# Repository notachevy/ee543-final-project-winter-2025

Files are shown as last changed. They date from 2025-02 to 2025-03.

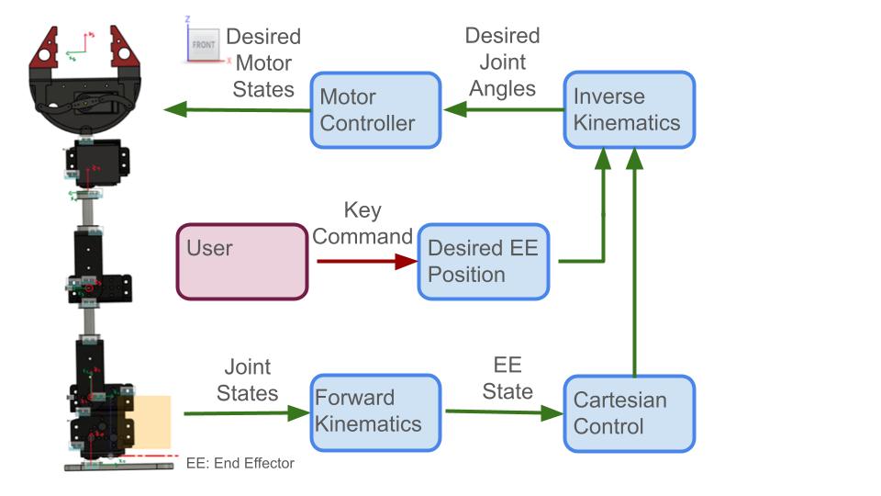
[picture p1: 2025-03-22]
Control Diagram.jpg

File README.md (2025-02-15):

# ee543-final-project-winter-2025
Devansh Bajwala, Nathan Ford, and Ahn Nguyen

## Instruction Document: https://docs.google.com/document/d/1Ubh2IKTzpHcgaXKEUiXXJ3vKN5BsKgkgP82SdHQJfz0/edit?tab=t.0
## Google Drive: https://drive.google.com/drive/folders/1BTNabRJ4Ctvt-MD4dDE4fDTYfD7tWb_S?usp=drive_link

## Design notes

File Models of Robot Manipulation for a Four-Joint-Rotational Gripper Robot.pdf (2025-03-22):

University of Washington Internal Report

# Models of Robot Manipulation for a Four-Rotational-Joint Gripper Robot

Devansh Bajwala
Dept. Of Mechanical Engineering University of Washington
Seattle, United States
db7529@uw.edu

Nathan Ford
Dept. Of Electrical Engineering University of Washington
Seattle, United States
naford@uw.edu

Anh Nguyen
Dept. Of Electrical and Computer Engineering
University of Washington
Seattle, United States
anguye22@uw.edu

Abstract— The field of robotics consists of many groundbreaking robotic advancements, but the robot detailed in this report is not one of them. The robot detailed in this report is a four-rotational-joint gripper robot that uses forward kinematics to enable joint-based control and inverse kinematics to enable cartesian control of the end effector. The robot was created to detail the basic principles of 3D robot manipulation. Rather than being a standard 6 degrees of freedom, the robot is instead 4 degrees of freedom. The 4 degrees of freedom present several challenges to the design and implementation process. The reachable workspace is approximated with a Monte-Carlo simulation that calculates whether a desired end effector position is achievable. The robot is modelled in software and created in physical hardware. The GitHub repository detailing the code and files necessary
to | recreate | the | robot | can | be | found | at | this | link:
https://github.com/notachevy/ee543-final-project-winter-2025.git. The project is based upon a template project provided in the GitHub repository found at this link: https://github.com/HaonanPeng/EE543-Robot-Manipulation-Project.git [1].

Keywords— Robotics, cartesian control, reachable workspace, rotational joints, link frame assignment, DH table, DH parameters, forward kinematics, inverse kinematics, IKBT, Monte-Carlo simulation.

I. INTRODUCTION
The study of robotics consists of mathematically modelling the positions of and relationships between links and joints to achieve interactions with the environment through an end effector. Robotic arms have a base that defines their set connection to a location and an end effector that allows it to interact with its environment. For our robot, the end effector is set as a gripper that is able to open and close, but many types of end effectors exist.
The current field of robotics is generating significant improvements in the medical field such as surgical robots. Across all fields, machine learning and artificial intelligence (AI) are helping robots interact with their environment by both aiding in physical training and allowing for virtual training through generated scenarios. Some robots focus on modelling human behaviour, but a majority of robots do not attempt to mimic human behavior but rather accomplish a task in an efficient manner. For 3D cartesian movement, a robotic arm is excellent as it usually provides 6 degrees of freedom, a perfect match to a 3-dimensional space. Advanced robotic arms have 7 degrees of freedom to allow for multiple arm positions, yielding the same end effector position. The advantage of multiple arm positions is that the robot arm can manipulate around obstacles and take predefined paths. The complexity when adding a 7th degree of freedom increases dramatically as the arm will always have multiple solutions, and control code will need to be written to determine the best solution instantaneously and over a pathway.
The more advanced robots will also utilize velocity control using the Jacobian. Velocity control allows for a robot arm to dictate its linear speed with calculations from its angular speed. The advantages to velocity-based control methods are smoother trajectories with fewer overshoots that help protect the robot and its surroundings. The generated trajectories have predefined acceleration paths, and if using a parabolic blend trajectory generation, faster movements from desired locations can be achieved.

II. LINK FRAME ASSIGNMENT AND DH PARAMETERS
To begin work modeling the robot, the graphical and mathematical representations of the robot must be defined. The robot is defined graphically by its link frame assignment and mathematically by its DH parameters, represented in a DH table.
A. Link Frame Assignment
The first step in defining a robot graphically is to define the base frame. The base frame for the robot is defined as the point the center point of the rotational disk meets the base. The +Z axis is defined as a perpendicular line that runs through the center of the rotation disk in the direction of the motor. The next step is to define the location of the final frame (frame five). The final frame is defined as a point in the middle of the grabber with the +Z axis defined as the direction facing outwards from the gripper. The +Z axis assignments can be seen in Fig. 1.
The +X direction of the base frame is set to be parallel to the +X direction of frame one. The +X direction of frame five is defined as parallel to the +X direction of frame four. The rest of the +X directions are assigned using standard DH assignment principles. The +Y directions are omitted from representation as they can be determined by taking the cross product of +Z cross +X. The +X assignments can be seen in Fig. 1.

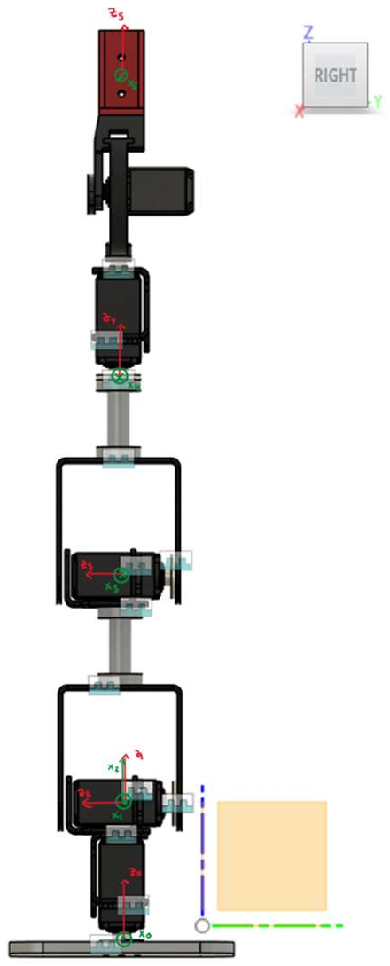
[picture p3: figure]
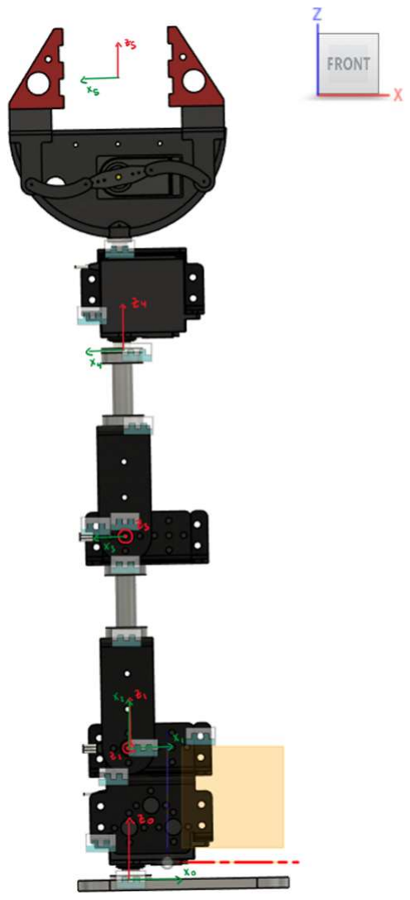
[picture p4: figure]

Fig. 1. Link frame assignment overlayed onto 3D model of robot. Perspective cube in top right corner represents world view orientation and direction. Red, green, and blue dashed lines represent world view axis in X, Y, Z format respectively. The yellow plane represents the face of the model (as seen in the perspective cube in the top right corner).

B. DH Table and Parameters
To define a robot mathematically, its graphical representation can be used to define a set of parameters representing the rotational and translational transforms necessary to go from one frame to the next frame. Standard DH parameter assignment is used to get the DH parameters shown in Table I.

TABLE I. DH PARAMTERS

Joint
N-1 N

DH Parameters
| A (mm) | α (deg) | d (mm) | θ (deg)
0 1 | 0 | 0 | 62.8 | θ
1 2 | 0 | 90 | 0 | θ
2 3 | 101 | 0 | 0 | θ
3 4 | 0 | 90 | 87.5 | θ
4 5 | 0 | 0 | 125 | 0
C. Forward Kinematics Simulation
The previously provided CAD model of the robot arm is excellent at visualizing what the arm will look like but poor at indicating how the arm will move and showing the current state of the robot. To visualize the frames of the arm while it is moving, a forward kinematics simulation models the motion of the arm. The simulation shows the robot arm modelled as simple links in an empty 3D space. The length of the virtual link joints is proportional to the size of the actual arm links. Each link frame is represented with a red arrow indicating the +Z direction and a blue arrow indicating the +X direction. A snapshot of the simulation can be seen in Fig. 2.

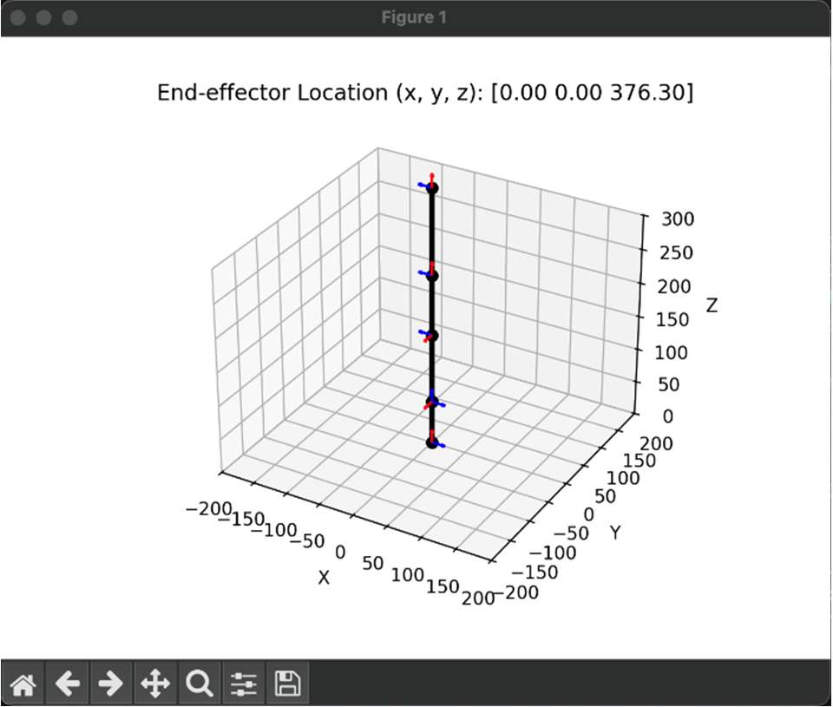
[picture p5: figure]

Fig. 2. Forward kinematics simulation showing a virtual representation of the actual arm. The virtual link lengths are proportional to the actual link lengths. Each link frame assignment is shown by indicating the +Z direction with a red arrow and the +X direction with a blue arrow. The robot is shown in the “home” position, or its state when all the servos are homed and their theta values are set to 0.
The simulation is computed using a numeric solving of the forward kinematics equations. The forward kinematics are updated every time a joint angle is changed to display the position of the actual arm in real time. The details of determining the forward kinematics are given in the next section, Forward Kinematics.

III. FORWARD KINEMATICS
Forward kinematics is the process of applying the state of a robot represented by its rotational joint angles and translational joint distances to determine the orientation and location of the end effector in space. For the four-rotational-joint gripper, only rotational joints are used so only rotational joints will be discussed. Translational joints behave mathematically similar to rotational joints except the “d” value from the DH table is variable while the “θ” value is fixed.
Forward kinematics will provide the end effector position given the input joint angles result in a valid orientation. The collection of all valid robot joint angles is called the reachable workspace. The workspace is a complicated 3D space, so a Monte-Carlo simulation is run to visualize and approximation of the workspace. The Monte-Carlo simulation samples many random valid combinations of joint angles to produce a point-cloud of valid end effector positions, giving a visualization of valid end effector positions.
A. Symbolic Forward Kinematics
To computationally save time to calculate the forward kinematics for every instance of the robot, the symbolic representation of the end effector can be found in terms of the angles of its joints. The symbolic representation begins as a collection of transformation matrices that contain a rotation matrix and a position vector. These transformation matrices use the DH table to generate a transformation matrix for the transformation between every frame, 01, 12, 23, 34, and 45. Because each transformation is calculated in the current frame, the total transformation matrix from the base to the end effector, 05, can be found by post-multiplying the transformation matrices in order. The individual transformation matrices are given in Fig. 3.

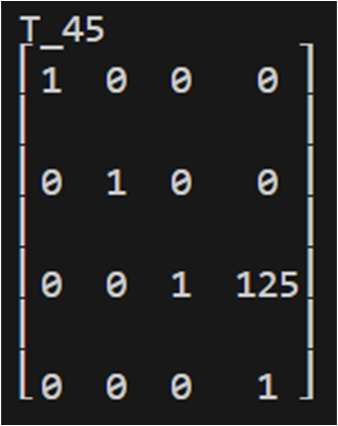
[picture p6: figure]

Fig. 3. Forward kinematics transformation matrices. The transformation matrices represent the rotation matrix (the upper left 3x3 matrix) and the position vector (the upper right 1x3 matrix). From top to bottom, the figures are: a. general transformation matrix form showing the location of the rotation matrix and position vector with a graphical representation of the transformaiton [2], b. the transformation matrix from frame 0 to frame 1, c. the transformation matrix from frame 1 to frame 2, d. the transformation matrix from frame 2 to frame 3, e. the transformation matrix from frame 3 to frame 4, f. the transformation matrix from frame 4 to 5.
The overall transformation matrix to go from the base frame to the end effector frame, 05, is quite complicated. The full transformation matrix in Fig. 4 is included for completeness, but for ease of use, the “forward_k.py” file should be run from the project GitHub to acquire the matrix if it is to be used. The full transformation matrix is useful as it allows for a simpler calculation of end effector position given joint angles. Only twelve values need to be calculated given four variables to determine the orientation and location of the end effector. The symbolic representation speeds up calculations as numeric versions of each individual transformation matrix do not need to be multiplied together.

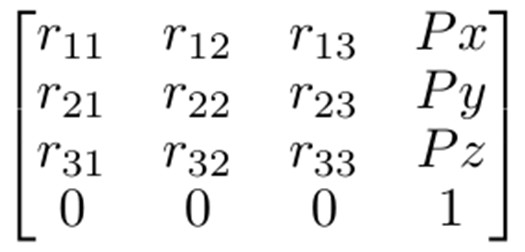
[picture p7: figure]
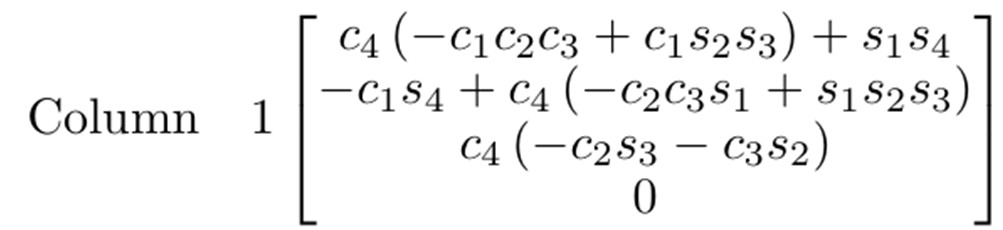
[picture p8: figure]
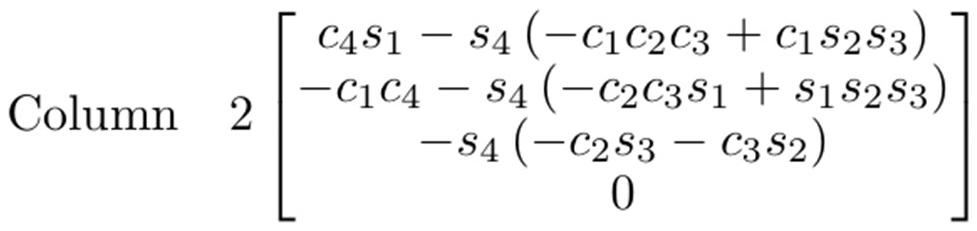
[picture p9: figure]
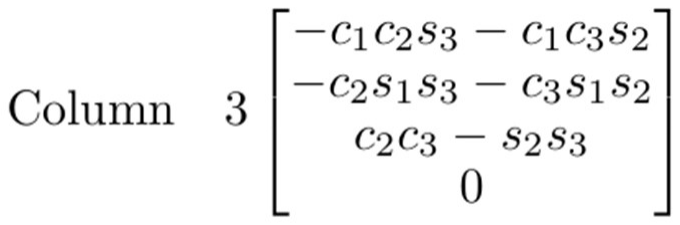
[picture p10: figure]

Fig. 4. The overall transformation matrix from the base frame to the end effector in general form (top). The individual columns are broken up to enhance

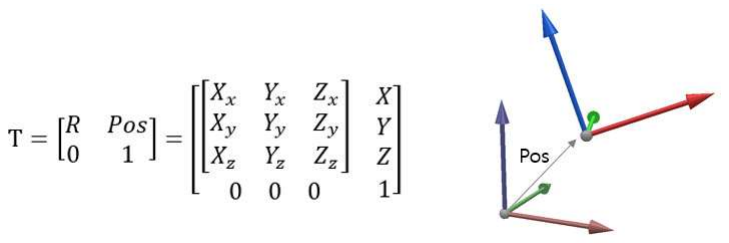
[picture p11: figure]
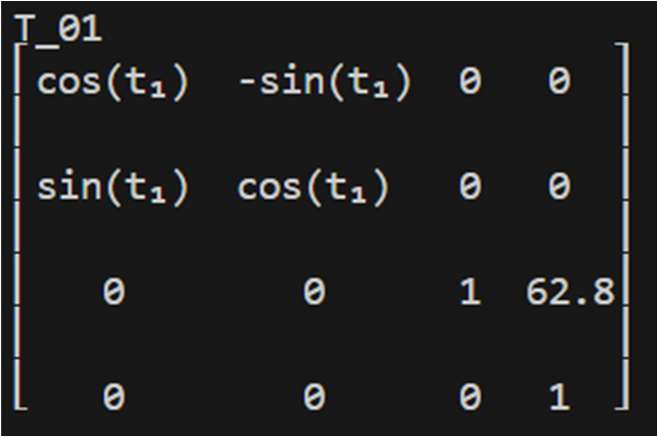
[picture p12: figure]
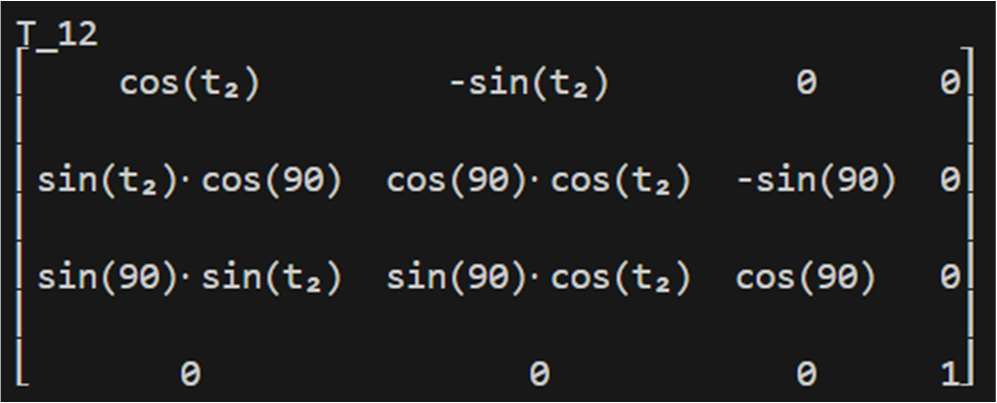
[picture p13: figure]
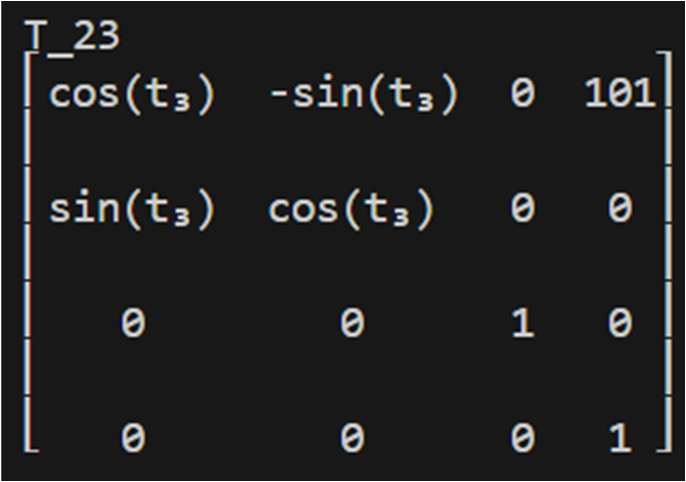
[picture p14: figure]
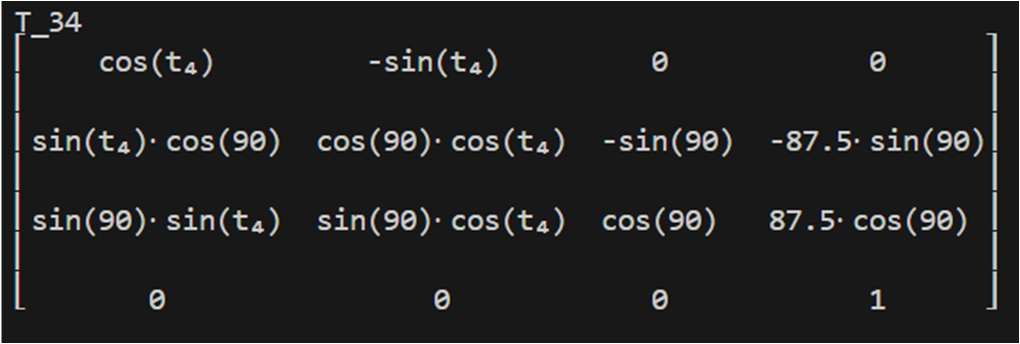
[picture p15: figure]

the readability of the symbolic forward kinematics matrix. The columns are numbered 1-4 and read from left to right.

B. Monte-Carlo Simulation
The Monte-Carlo simulation has two uses. The first use is to visualize the workspace and the second is to check if a given point is within or outside the workspace.
Visualizing the workspace is done by taking a large collection of random combinations of joint angles and using the previously discussed symbolic forward kinematics to determine the resulting end effector location. For this simulation, the orientation of the end effector is ignored as the workspace is defined as the region the end effector can reach. Each iteration of the simulation plots one point in 3D space for a valid joint combination. With numerous iterations, a point cloud forms that shows the shape of the 3D workspace. The Monte-Carlo workspace approximation is shown in Fig. 5. The simulation yields a workspace that appears spherical. In practice, the arm is situated on a flat physical surface that prevents the arm from reaching points underneath it. In theory, the arm can reach all points within an outer boundary sphere and outside and inner boundary sphere (components cannot physically overlap).

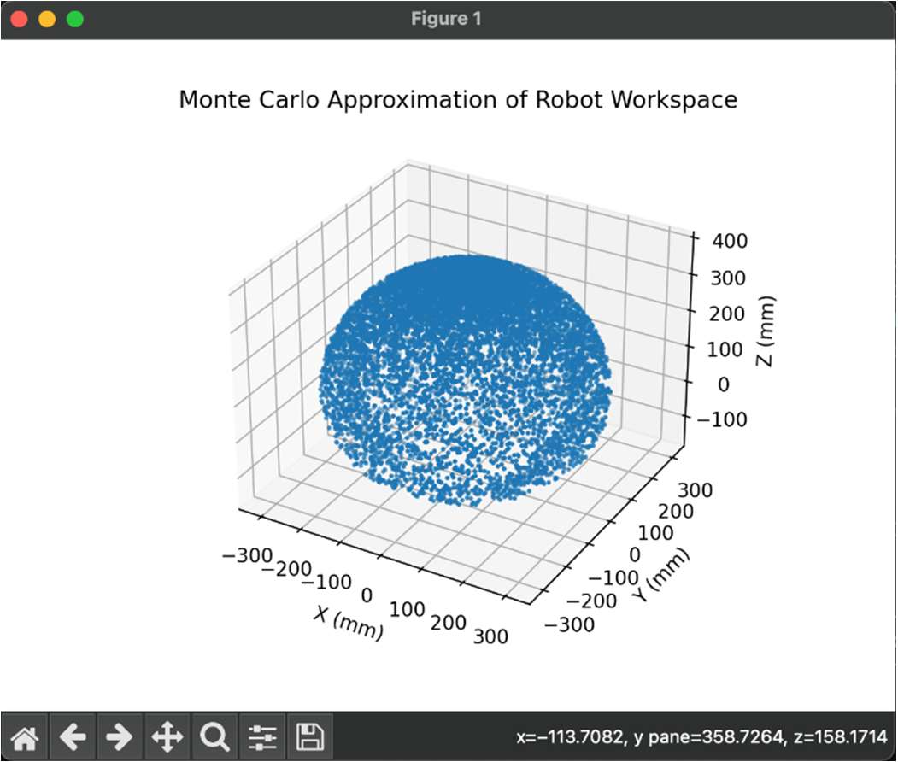
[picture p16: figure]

Fig. 5. Monte-Carlo simulation showing a point cloud that approximates the workspace of the robot by plotting the end effector location by plugging in angles into the symbolic forward kinematics and solving using numerous iterations of combinations of valid joint angles.
The second use of the Monte-Carlo simulation is to determine whether a given point is reachable in the workspace. Determining whether a point is within the workspace is helpful in determining the validity of a combination of joint angles to ensure the safety of the robot and the users nearby. To calculate whether the point is within the workspace, the algorithm will sample the nearest points in the cloud and create vectors between the test point and each closest point. The algorithm will then compare the angle between the closest vectors to see whether or not the point is within the tangent of the workspace. To accomplish this, any angle above 85 degrees is assumed close enough to 90 degrees to warrant being within the workspace.

To test the algorithm, three points are given and the algorithm needs to determine whether or not the points are within the workspace. The results are shown in Fig. 6 and Table II.

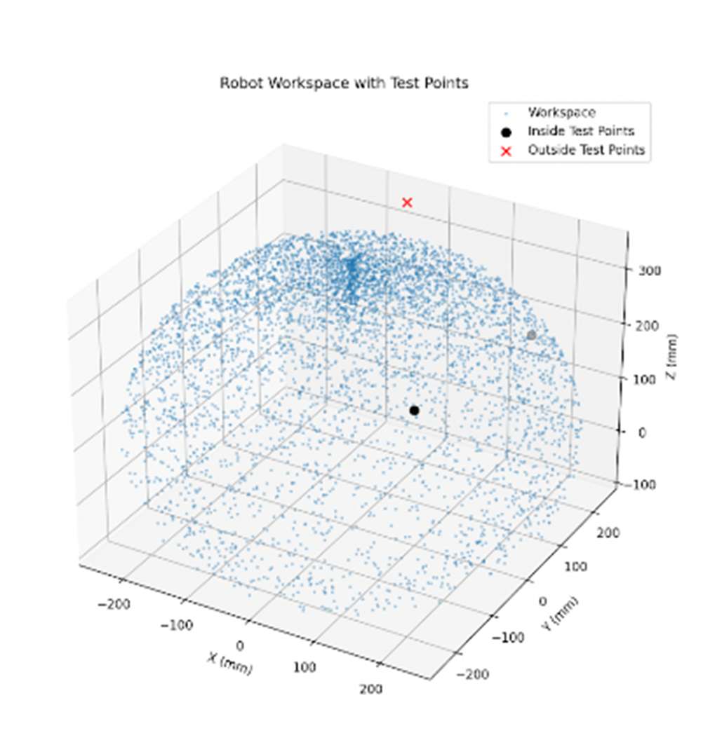
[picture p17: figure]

Fig. 6. Monte-Carlo workspace simulation showing test points and whether or not they are within the workspace.

TABLE II. | MONTE-CARLO WORKSPACE TEST POINTS
Point | Point Parameters
X | Y | Z | Inside or Outside Workspace
1 | 70 | 50 | 100 | Inside
2 | 175 | 150 | 400 | Outside
3 | 180 | 180 | 200 | Inside

IV. INVERSE KINEMATICS AND CARTESIAN SPACE CONTROL
Inverse kinematics is both more complicated and more useful than forward kinematics. Inverse kinematics is the inverse of forward kinematics, where a known end effector position is used to determine the joint angles to produce the desired position and rotation. Unfortunately, for our robot, we have four joints and only three known values, X, Y, and Z. This means our situation is underspecified and there may be multiple solutions. This trouble arises from our robot only having 4 degrees of freedom rather than the standard 6 degrees of freedom associated with X, Y, Z, roll, pitch, and yaw. To keep functionality of our robot, the final rotational joint is perpendicular to the direction of motion of the grabber. This means with one rotational joint; we can control our orientation and do not need to solve for all 6 degrees of freedom.
For our robot, we explored both analytical inverse kinematics and numerical inverse kinematics to achieve

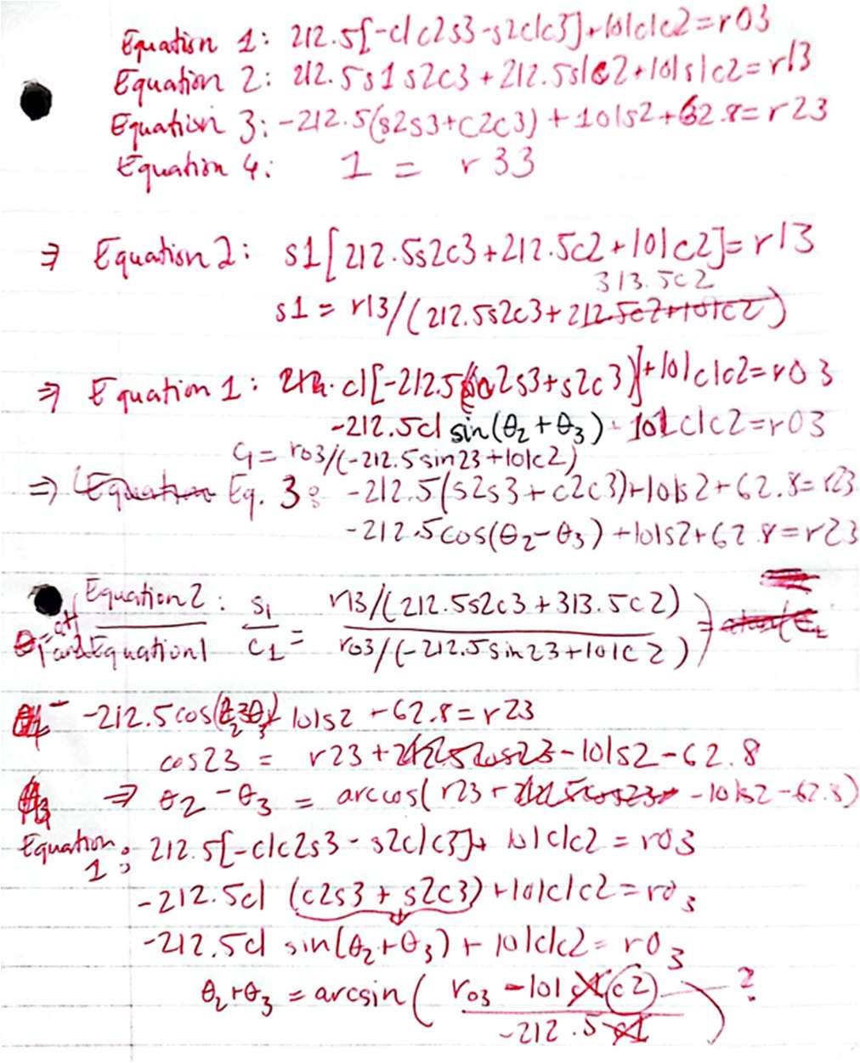
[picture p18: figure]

cartesian control rather than joint control. The analytical inverse kinematics is too complicated to be handled by solvers such as Wolfram-Alpha, so it needed to be attempted manually. Our attempt to solve the inverse kinematics by hand was unsuccessful and we ended up using a prebuilt IKBT library made by Professor Blake Hannaford to compute the analytical inverse kinematics solution [3]. For the actual implementation, numeric inverse kinematics was solved using an optimizer to minimize the error between desired and actual end effector position with respect to joint angles.
With solved inverse kinematics, the end goal of controlling the end effector in cartesian space can be achieved. Cartesian control is more intuitive for operators than joint control, so it is preferred even though it is more computationally difficult.
A. Analytical Inverse Kinematics
To quickly solve the joint angles required, an analytical solution will yield symbolic representations of the joint angles. These symbolic representations are significantly faster to compute than a numeric approximation of joint angles. To compute the analytical solution to the inverse kinematics, the forward kinematics solution from the base to the end effector is taken and solved for the joint angles.
To solve for the joint angles, there need to be known values in the transformation matrix. Unfortunately, we are assuming for our cartesian control that we do not have control over the orientation of the end effector directly. To orient our end effector, we are using the rotational joint connected to the gripper, joint 4. Having control over X, Y, Z, and roll (in the direction of +Z axis) means our robot arm only has 4 degrees of freedom rather than the standard 6 degrees of freedom in 3D space. Because we are solving our inverse kinematics for the cartesian control, we are assuming the only three known values are X, Y, and Z. When solving for the joint angles, joint 4 does not impact the end effector position, so we only need three equations to solve for joints 1, 2, and 3. The three equations that dependent upon joints 1, 2, and 3 conveniently are the equations for X, Y, and Z. With these equations to solve determined, we began the task of isolating for each joint angle. Unfortunately, the joint angle dependencies made it too difficult to isolate the variables by hand. With the equations isolated, we tried an online solver to solve for the joint angles, but the system of equations proved too difficult for Wolfram Alpha to solve as well. The manual and Wolfram Alpha attempts to solve for the joint angles are shown in Fig. 7.

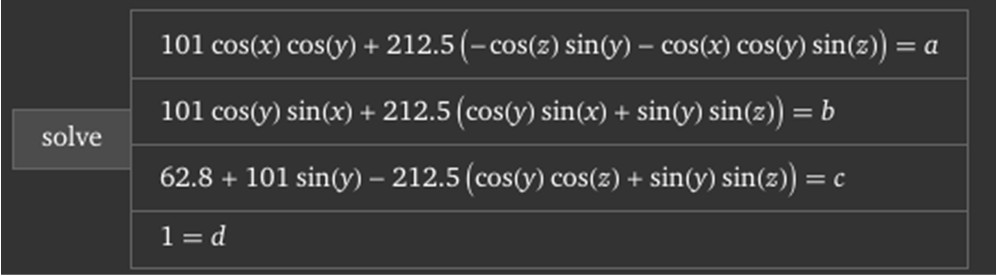
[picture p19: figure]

Fig. 7. Manual (top) and Wolfram Alpha (bottom) attempts at solving for the joint angles 1, 2, and 3. The manual attempt details attempts at solving for the joint angles theta 1 with theta 2 and theta 3 dependenceies. Theta 2 and theta 3 could not be isolated from each other. The Wolfram Alpha attempt at solving did not yield a solution or formal attempt as the complexity is greater than it can compute.
Because the manual analytical inverse kinematics was unsuccessful, we turned to an existing library to assist with solving our inverse kinematics. The library is based upon Professor Blake Hannaford’s work in solving inverse kinematics with symbolic behaviour trees (called IBKT in the given GitHub link above). The process involves finding closed-form solutions to inverse kinematics problems with actions in behavior trees. The library generates a report called “IK_Report_Template” that is visible on our project GitHub repository. Fig. 8 Shows the joint angle solutions while Fig. 9 shows the dependencies between joint angles.

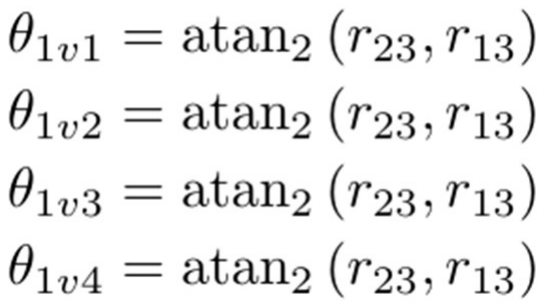
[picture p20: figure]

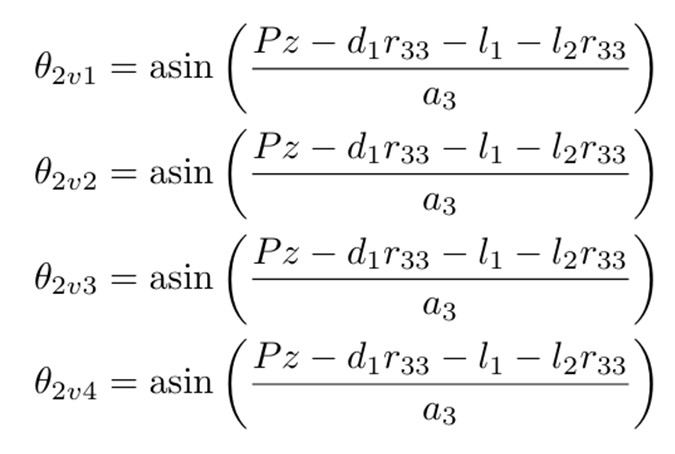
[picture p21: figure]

Fig. 8. IKBT inverse kinematics solutions for joints 1 through 4. Solutions found using IKBT library [3]. More legible versions of the solutions can be found on the project GitHub under the file: “ik_report_template.” From theta 1 to theta 4 and then theta 23, the methods used to solve for each joint angle are as follows: arctan2(y, x), arcsin(y), arctan2(y, x), arctan2(y, x), and algebra.
In the solutions, some joint angles have multiple solutions and are dependent upon the multiple solutions of other joint angles. To clarify the connections between multiple joint angle solutions and their dependencies, a dependency graph is provided in Fig. 9.

Fig. 9. IKBT graphical edge connections showing theta dependencies where “th” represents the joint angle and “-->” represents the direction of the dependency.
Unfortunately, because the IKBT solver uses the rotation matrix (r: r), the solutions cannot be implemented into the code. The implementation of the robot does not have the 6 degrees of freedom required to utilize the rotation matrix fully. Because of this, a numeric approach to solving the inverse kinematics was used in the code.
B. Numerical Inverse Kinematics
For simplicity’s sake, a numerical inverse kinematics solver is significantly easier from an implementation standpoint. From a computation viewpoint however, numerical inverse kinematics is significantly slower than analytical inverse kinematics.
To accomplish the numerical inverse kinematics, the scipy optimize package was used to minimize the error between the current and desired end effector location. The algorithm tries different combinations of joint angles until it converges to the solution with the lowest error. The final joint angles are determined to be the estimated solution to the inverse kinematics equation. To ensure convergence, the SLSQP optimization method was used. This method will allow convergence on desired locations outside of the workspace and prevent the arm controls from crashing. The optimizer uses normalized joint angles, so the bounds of the optimization have to be set to ensure the optimizer only tries valid joint angles. The optimization works best in small steps to avoid alternate solutions, so the inverse kinematics function is run several times on intermediate points rather than just once from a desired starting and stopping point. The smaller steps allow for smoother and more consistent motion from the arm. The code, including the optimization, is shown in Fig. 10.

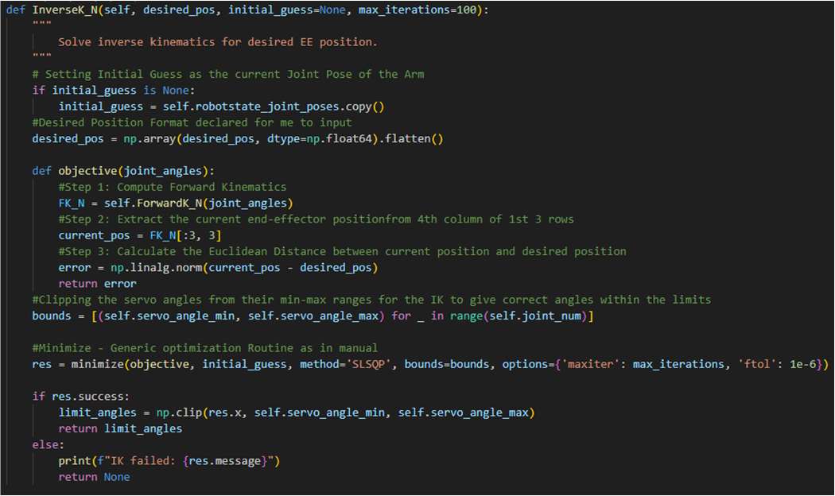
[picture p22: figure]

Fig. 10. Code for the numeric inverse kinematics solver. The minimize function is used to iteratively determine numeric approximations of joint angles required to reach the desired end effector position. The numeric approximation will converge for any point entered, within or outside the workspace.

C. Cartesian Control
The goal of the project was to use a computer keyboard to control the location of the end effector in cartesian space. The end effector could have it orientation changed with the rotation of joint 4 and manipulate objects by opening and closing the gripper. With this functionality, we attempted picking up a small cylinder and moving it to another location.
During our demonstration, we were able to use a predefined trajectory to have our robot pick up a small object and drop it in a designated bin in a different location. Both the start and end locations are given in [X, Y, Z] format. The robot moves from the home position, [0, 0, 376.30] to the desired pick-up location and closes the gripper. Once the gripper is closed, the robot moves from the pick-up location to the desired drop-off location. The robot then opens the gripper at the target destination. A video demonstration of this can be found in the GitHub repository for the project.
The control code was difficult to implement but simple conceptually. The control code workflow is depicted in Fig. 11 and shows the process for cartesian control with user interaction.

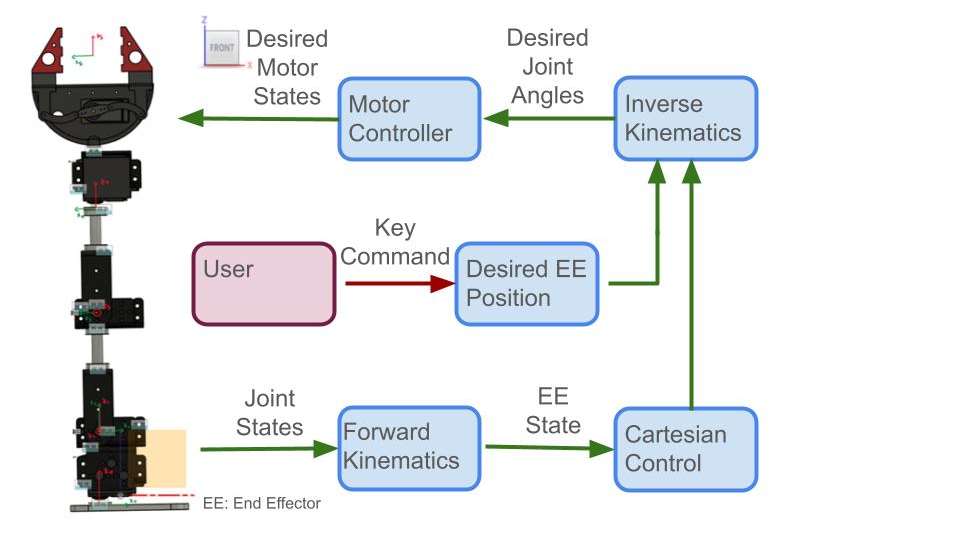
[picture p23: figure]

Fig. 11. System workflow where blocks show processes and arrows show information transfer.
Due to human error and potential miscalculations, we were unable to solve the symbolic inverse kinematics analytically by hand. Therefore, we used an external IKBT library instead to figure out the results. The library yielded results that required the rotation matrix, something our 4 degrees of freedom could not manage. Because of this, we were unable to implement the symbolic inverse kinematics into our control code. With only a functional numeric inverse kinematics solver, the runtimes of the numeric and analytical solvers cannot be compared experimentally. Ideally, the analytical solve would be faster as a closed-form solution is known and requires minimal-compute time. With just the numeric solver, undesirable behavior can be seen in how point queries can take up to twice as long as other queries. Query time inconsistency is undesirable in ensuring smooth and accurate robot manipulation. The numerical inverse kinematics runtimes for the three previously discussed points is provided in Table III.
TABLE III. | ANALYTICAL VS. NUMERIC INVERSE KINEMATICS SOLVE TIMES
Point | Inverse Kinematics Method
Analytical Solving Time (ms) | Numeric Solving Time (ms)
1 | N/A | 5.52
2 | N/A | 4.76
3 | N/A | 10.8
V. CONCLUSION AND FURTHER WORK
The goal of the project was to use a computer keyboard to control the location of the end effector in cartesian space – this goal was achieved. Additional goals were attempted but not completed. These areas for further work include determining an analytical solution manually, completing velocity-based control using the Jacobian, and avoiding harmful singularities. All areas are within the capabilities of the team but not feasible within the time constraints given.
After completion of the basic robot, additional uses of the robot have been devised by team members and two main pathways have been determined: Computer Vision and Autonomous Operation and Teleoperation.
The current functionality of the robot arm allows for movement to specified [X, Y, and Z] coordinates. An application that takes advantage of this would be to implement computer vision to identify the target object and target location (in our demo, a waste basket). With the object and destination identified, their locations could be determined from the camera’s frame. Using similar frame transformations to the ones described in this paper, a transformation(s) could be calculated to represent the object and destination in the base frame of the robot to allow for end effector interaction.
Along with the completion of this robot, five additional robot arms were prepared simultaneously by additional teams. With their creation of additional arms, one team incidentally created the same physical robot arm as the one described in this paper.
With | two | identical | robots, | teleoperation | becomes
straightforward as the joint angle mapping becomes 1:1. One robot arm is able to directly mirror the other. With mirroring robot arms, a remotely operated arm can be controlled by a human user with deeper critical thinking than can be programmed. The human operator allows for completion of complex and novel tasks.
Overall, the development of a basic four-rotational-joint gripper robot allowed for significant development of robotics skills and the showcase of robot-environment interactions. The team is interested in the proposed future works and will continue their work in implementing advances in their robotic endeavors.

REFERENCES

[1] H. Peng, EE543 Robotic Manipulation Project, Seattle: GitHub, 2025.
[2] CoppeliaSim Robotics, "CoppeliaSim User Manual on Positions and
Orientations," | [Online]. | Available:
https://manual.coppeliarobotics.com/index.html. [Accessed 19 March 2025].
[3] B. Hannaford and D. Zhang, IKBT: Solving Symbolic Inverse Kinematics with Behavior Tree, Seattle: AI Access Foundation, 2019.

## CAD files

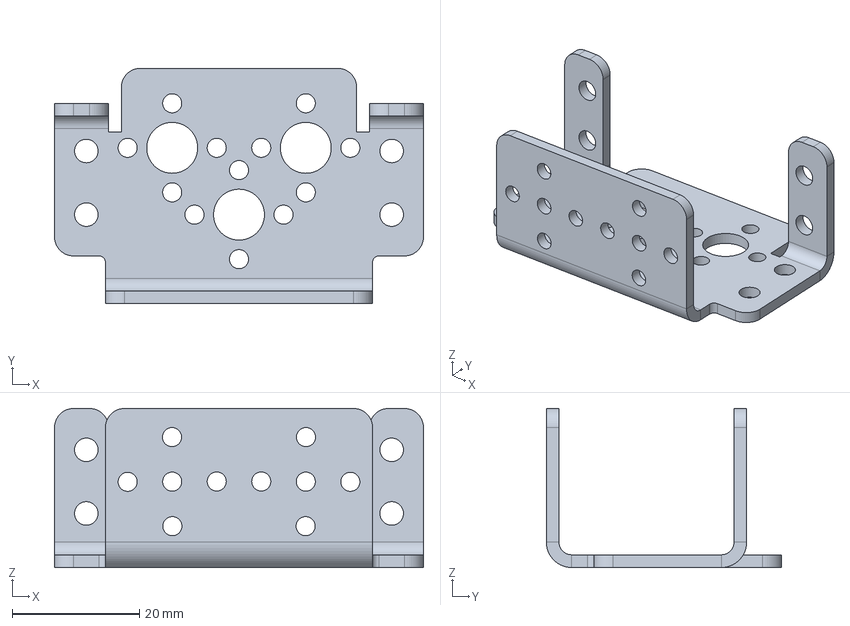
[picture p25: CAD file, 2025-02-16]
Arm_CAD/mg996-with-mount-1.snapshot.10/Servo Bracket - universal v10.step
58.0 x 37.0 x 25.0 mm

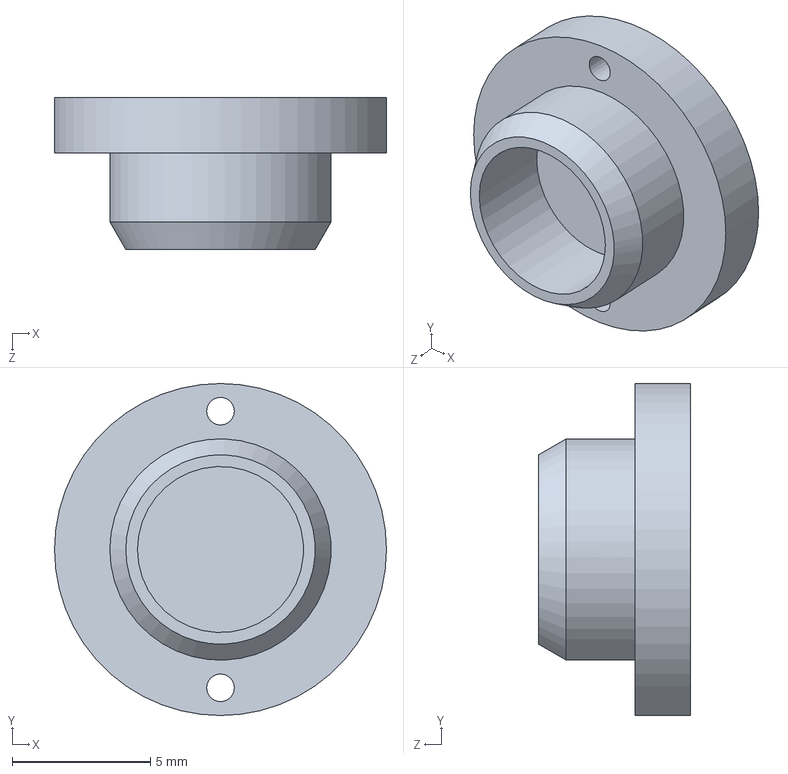
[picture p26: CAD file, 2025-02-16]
Arm_CAD/robotic-arm-gripper-5/holder.SLDPRT
12.0 x 12.0 x 5.50 mm

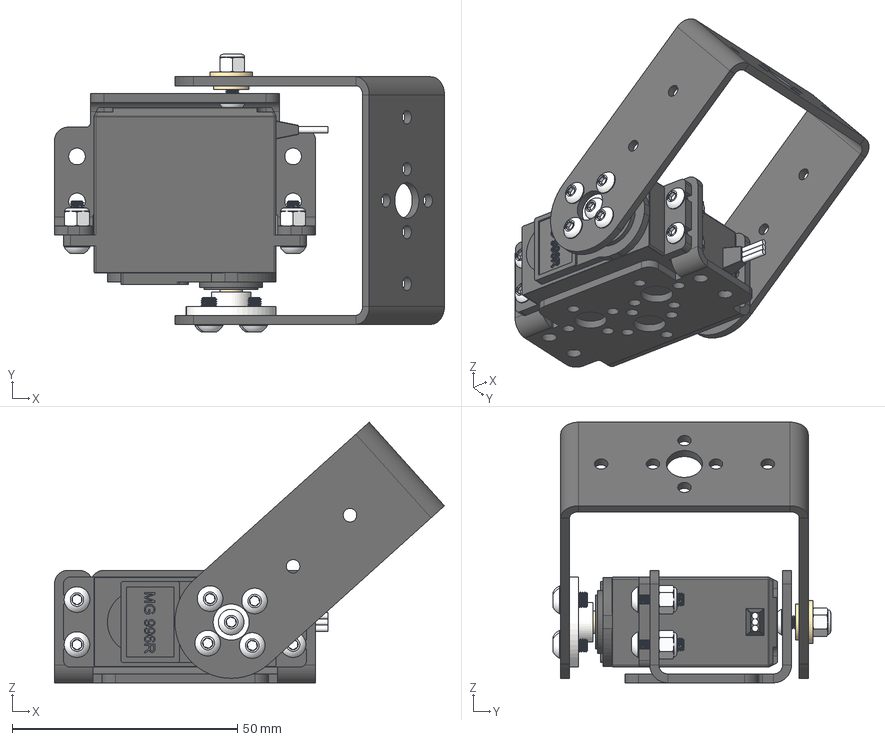
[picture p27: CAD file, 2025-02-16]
Arm_CAD/mg996-with-mount-1.snapshot.10/servo with bracket v9.step
86.6 x 61.7 x 57.9 mm
servo body
TowerPro-MG995_pulley v1
servo dise v1
Servo Bracket - universal
M3x10 x 5
M3 safe nut x 5
Servo Bracket - long U
brass brushing
M3x6 x 5

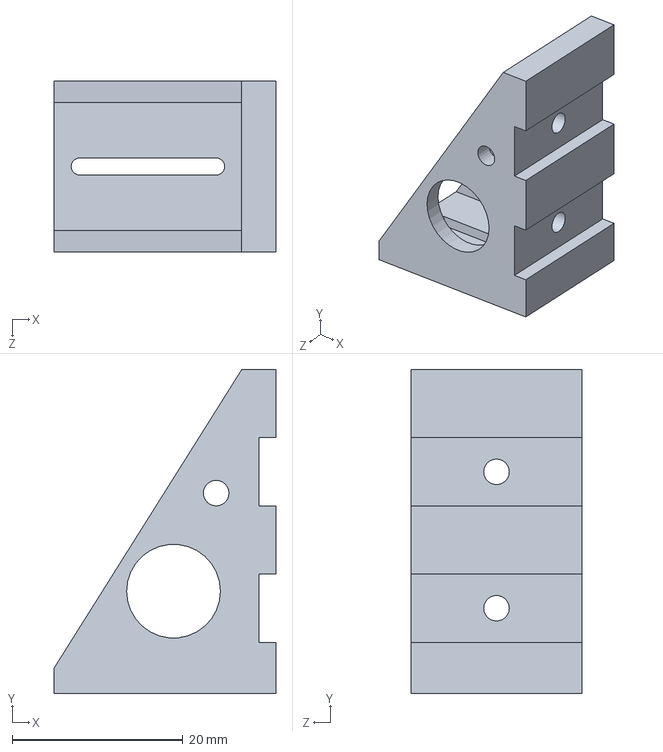
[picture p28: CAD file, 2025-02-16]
Arm_CAD/robotic-arm-gripper-5/Part2.SLDPRT
26.0 x 38.0 x 20.0 mm

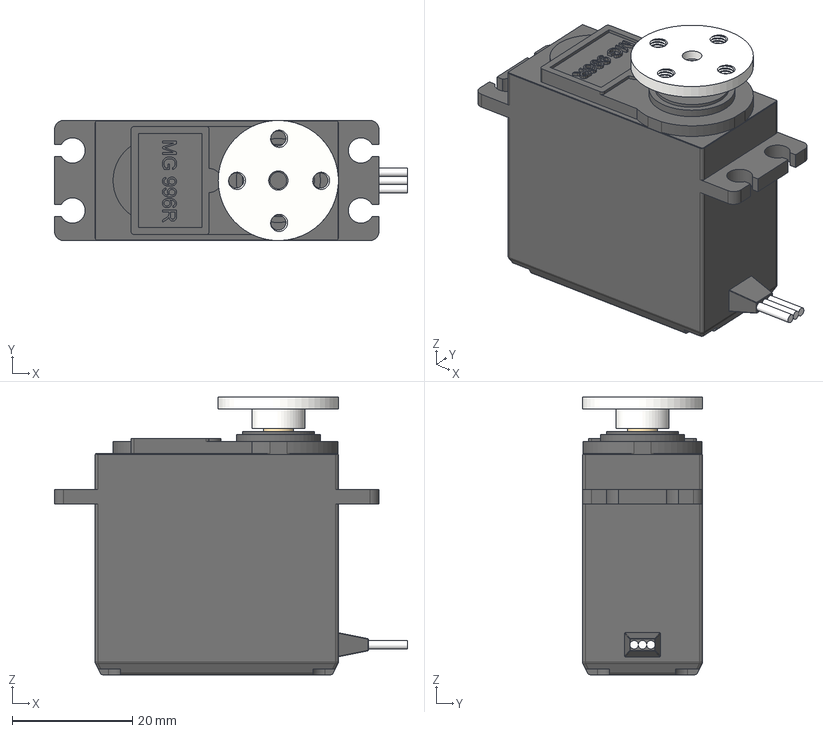
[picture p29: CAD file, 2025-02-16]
Arm_CAD/mg996-with-mount-1.snapshot.10/MG996 v1 v12.step
58.8 x 20.0 x 46.2 mm
servo body
TowerPro-MG995_pulley v1
servo dise v1

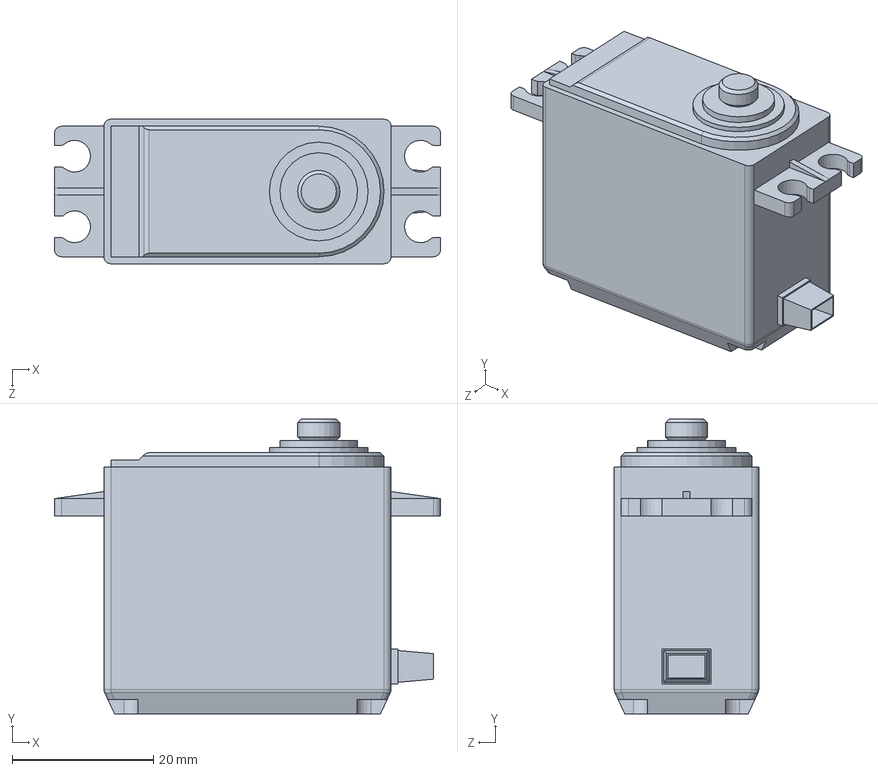
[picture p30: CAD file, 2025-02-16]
Arm_CAD/robotic-arm-gripper-5/Servo MG966R.SLDPRT
54.7 x 41.8 x 20.5 mm

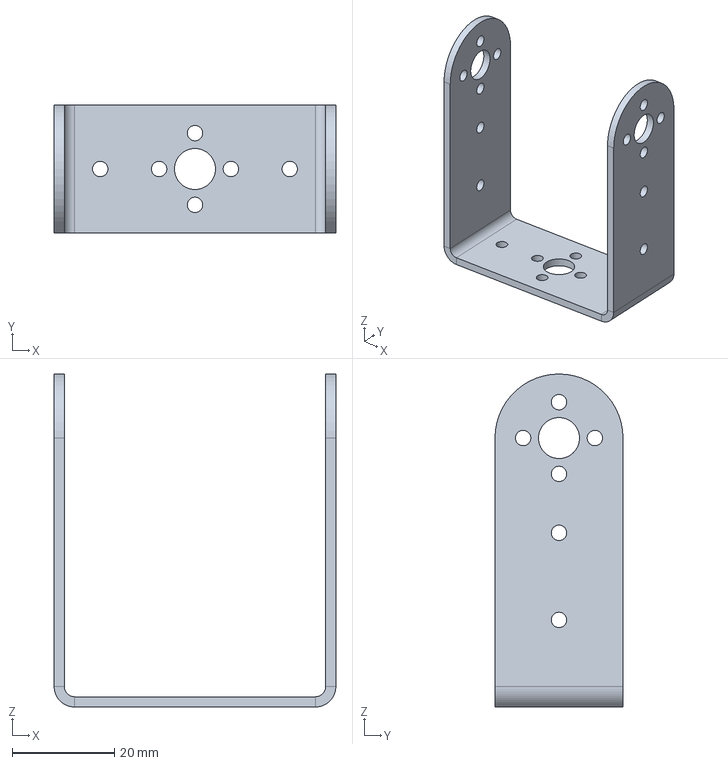
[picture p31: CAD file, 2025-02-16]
Arm_CAD/mg996-with-mount-1.snapshot.10/Servo Bracket - long U v3.step
55.0 x 25.0 x 65.0 mm

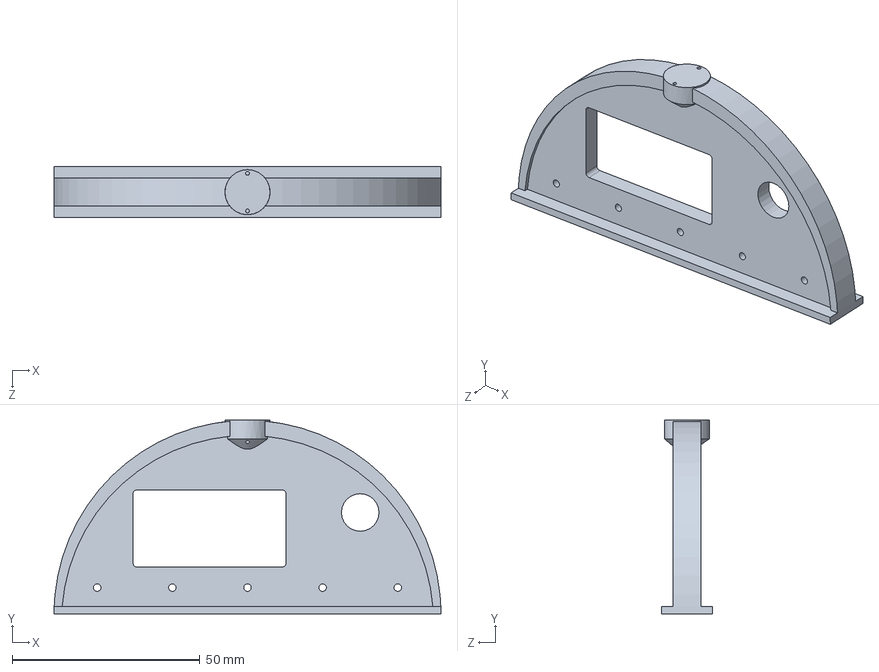
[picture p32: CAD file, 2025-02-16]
Arm_CAD/robotic-arm-gripper-5/Base.SLDPRT
103.0 x 51.6 x 13.5 mm

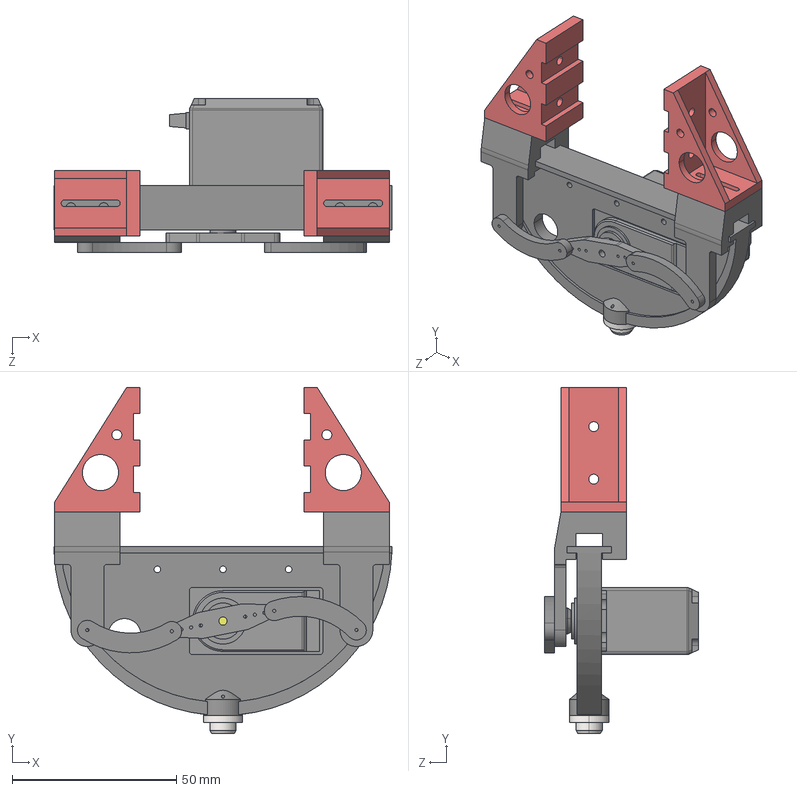
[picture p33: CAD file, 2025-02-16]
Arm_CAD/robotic-arm-gripper-5/gripper.STEP
103.0 x 105.6 x 46.9 mm
Estrella_Predeterminado
Cuerpo_Predeterminado
holder

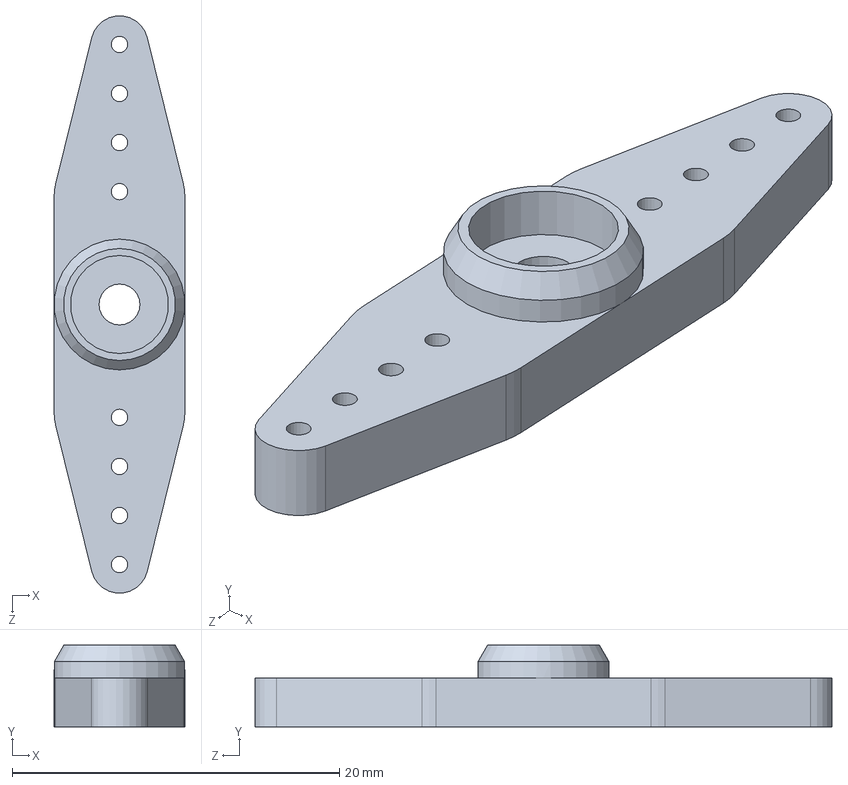
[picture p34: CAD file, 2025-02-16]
Arm_CAD/robotic-arm-gripper-5/Estrella.SLDPRT
8.00 x 5.00 x 35.3 mm

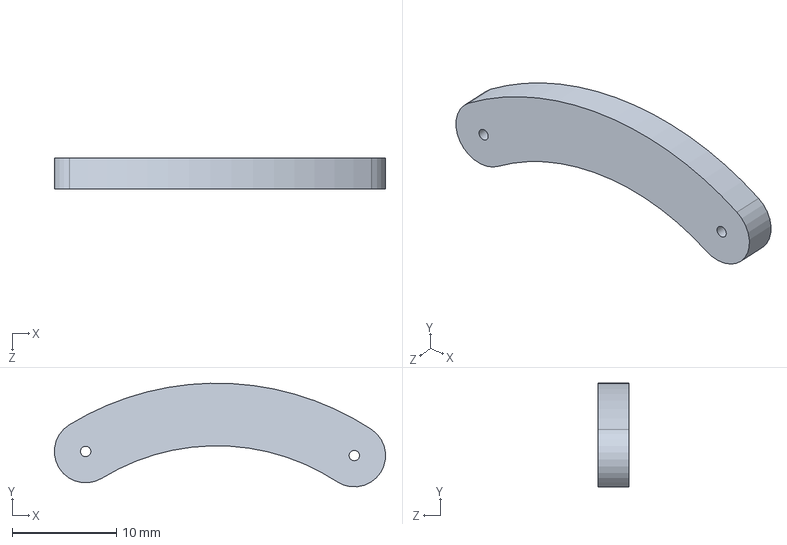
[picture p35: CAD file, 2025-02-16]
Arm_CAD/robotic-arm-gripper-5/Part4.SLDPRT
31.7 x 9.92 x 3.00 mm

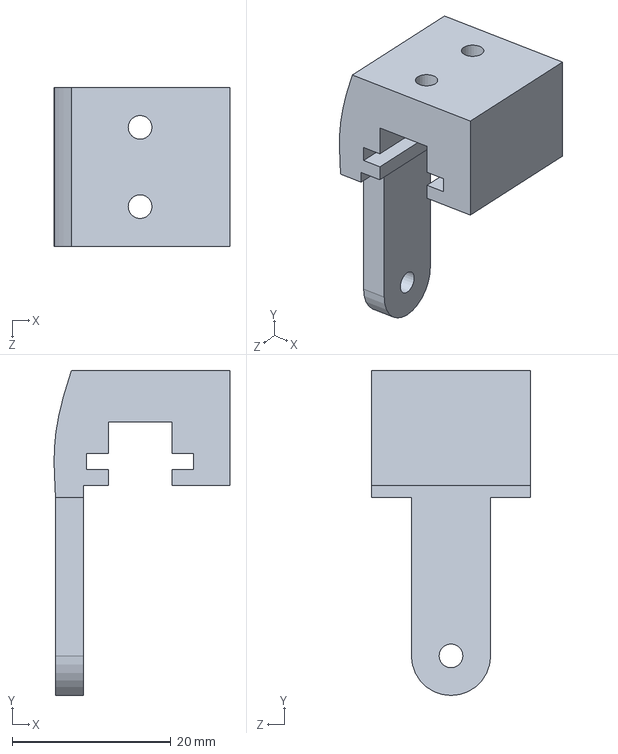
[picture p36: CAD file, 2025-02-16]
Arm_CAD/robotic-arm-gripper-5/Part3.SLDPRT
22.2 x 41.0 x 20.0 mm

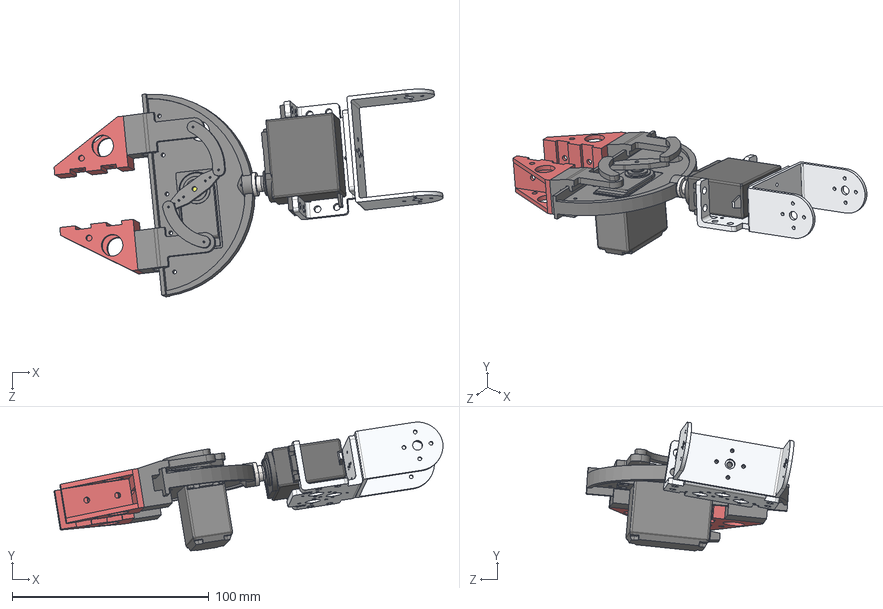
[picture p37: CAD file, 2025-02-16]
Arm_CAD/robotic-arm-gripper-5/Wrist.STEP
198.0 x 65.6 x 105.8 mm
Cuerpo_Predeterminado
Estrella_Predeterminado
holder
clamp_1
Servo MG966R
clamp_2

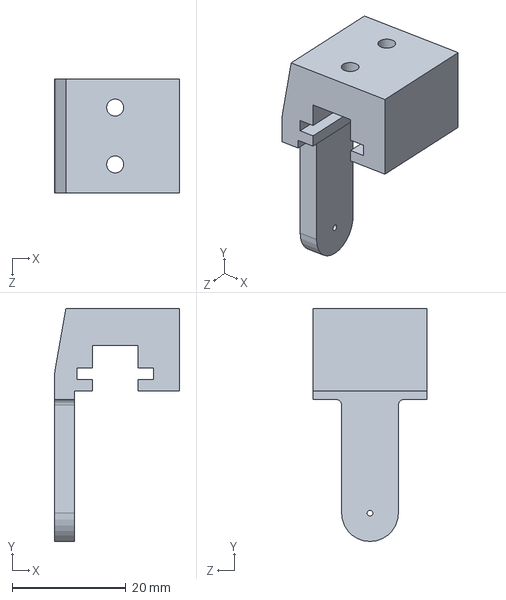
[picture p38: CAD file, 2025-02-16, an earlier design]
Arm_CAD/robotic-arm-gripper-5/Part3 (2).SLDPRT
22.0 x 41.0 x 20.0 mm

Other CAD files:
Arm_CAD/Arm Assembly v3.f3z
Arm_CAD/Arm Assembly v5.f3z
Arm_CAD/Arm Assembly v7.f3z
Arm_CAD/Offset Joint v4.f3d
Arm_CAD/mg996-with-mount-1.snapshot.10/MG996 v1 v12.f3d
Arm_CAD/mg996-with-mount-1.snapshot.10/Offset Joint.f3d
Arm_CAD/mg996-with-mount-1.snapshot.10/Servo Bracket - long U v3.f3d
Arm_CAD/mg996-with-mount-1.snapshot.10/Servo Bracket - universal v10.f3d
Arm_CAD/robotic-arm-gripper-5/gripper.SLDASM

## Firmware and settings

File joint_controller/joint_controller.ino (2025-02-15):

// For EE543 project, the amount of joints is 4
/*This version of firmware is for the arduino that will reset when the serial port is connected*/
#define JOINT_NUM 4

// Define communication protocal
#define INIT_UNO 'I'
#define ACK_UNO 'A' 
#define SIG_PC 'S'
char dump;

// Define state machine for serial communication
enum serial_states{IDLE, INIT, READY, STREAM, TIMEOUT};
enum serial_states serial_state;
// Define flag for event
bool PC_signal_flag = false;
bool serial_timeout_flag = false;

// Debug pin
// hook on the oscilloscope to confirm the frequency
const int debugPin_idle = 2;
const int debugPin_init = 3;
const int debugPin_ready = 4;
const int debugPin_stream = 5;
const int debugPin_timeout = 6;

void debug_pin_init()
{
  // set the digital pin as output:
  pinMode(debugPin_idle, OUTPUT);
  pinMode(debugPin_init, OUTPUT);
  pinMode(debugPin_ready, OUTPUT);
  pinMode(debugPin_stream, OUTPUT);
  pinMode(debugPin_timeout, OUTPUT);
  digitalWrite(debugPin_idle, 0);
  digitalWrite(debugPin_init, 0);
  digitalWrite(debugPin_ready, 0);
  digitalWrite(debugPin_stream, 0);
  digitalWrite(debugPin_timeout, 0);
}

void debug_pin_state()
{

  switch(serial_state)
  {
    case IDLE:
      digitalWrite(debugPin_idle, 1);
      digitalWrite(debugPin_init, 0);
      digitalWrite(debugPin_ready, 0);
      digitalWrite(debugPin_stream, 0);
      break;

    case INIT:
      digitalWrite(debugPin_idle, 0);
      digitalWrite(debugPin_init, 1);
      digitalWrite(debugPin_ready, 0);
      digitalWrite(debugPin_stream, 0);
      break;

    case READY:
      digitalWrite(debugPin_idle, 0);
      digitalWrite(debugPin_init, 0);
      digitalWrite(debugPin_ready, 1);
      digitalWrite(debugPin_stream, 0);
      break;

    case STREAM:
      digitalWrite(debugPin_idle, 0);
      digitalWrite(debugPin_init, 0);
      digitalWrite(debugPin_ready, 0);
      digitalWrite(debugPin_stream, 1);
      break;
  }
}

//include necessary library
// #include <wire.h>
#include <Adafruit_PWMServoDriver.h>

//create servo board object
// called this way, it uses the default address 0x40
Adafruit_PWMServoDriver pwm = Adafruit_PWMServoDriver();

//servo setting parameters
// Depending on your servo make, the pulse width min and max may vary, you 
// want these to be as small/large as possible without hitting the hard stop
// for max range. You'll have to tweak them as necessary to match the servos you
// have!
#define SERVOMIN  70 //-90 for mg996R// This is the 'minimum' pulse length count (out of 4096)
#define SERVOMAX  440 //+90 for mg996R// This is the 'maximum' pulse length count (out of 4096)
// #define USMIN  600 // This is the rounded 'minimum' microsecond length based on the minimum pulse of 150
// #define USMAX  2400 // This is the rounded 'maximum' microsecond length based on the maximum pulse of 600
// #define USMIN  150
// #define USMAX  600
#define SERVO_FREQ 50 // Analog servos run at ~50 Hz updates

// our servo # counter
// uint8_t servonum = 0;

//data array that store the Joint pose
uint16_t joint_poses[JOINT_NUM];
unsigned char buff[JOINT_NUM*2]; //raw data receive from serial port

void timer_setup(){
  cli();                      //stop interrupts for till we make the settings
  /*1. First we reset the control register to amke sure we start with everything disabled.*/
  TCCR1A = 0;                 // Reset entire TCCR1A to 0 
  TCCR1B = 0;                 // Reset entire TCCR1B to 0
 
  /*2. We set the prescalar to the desired value by changing the CS10 CS12 and CS12 bits. */  
  TCCR1B |= B00000100;        //Set CS12 to 1 so we get prescalar 256  
  
  // /*3. We enable compare match mode on register A*/
  // TIMSK1 |= B00000010;        //Set OCIE1A to 1 so we enable compare match A 
  
  /*4. Set the value of register A to 31250*/
  OCR1A = 31250;             //Finally we set compare register A to this value  

  sei();                     //enable the intrrupt, so that the serial port can receive message
}
void timer_int_en(){
  TIMSK1 |= B00000010;        //Set OCIE1A to 1 so we enable compare match A 
}
void timer_int_dis(){
  TIMSK1 &= B11111101;        //Reset OCIE1A to 1 so we disable compare match A 
}
void timer_reset(){
  //reset counter
  TCNT1 &= 0; // clear the counter value
}
void timer_en(){
  //re-enable timer
  TCCR1B |= B00000100; //set the prescale to 256
}
void timer_dis(){
  //disable timer
  TCCR1B = 0; // disconnect the counter from clock source
}

void setup() {
  // put your setup code here, to run once:
  //configure the serial port to communicate with PC
  Serial.begin(115200);
  // Serial.print("Controller begin");
  // Serial.println();

  //set the state machine to INIT
  serial_state = IDLE;

  // set the digital pin as output:
  debug_pin_init();

  //configure timer
  timer_setup();

  //configure the PCA9865 serboard
  pwm.begin();
  /*
   * In theory the internal oscillator (clock) is 25MHz but it really isn't
   * that precise. You can 'calibrate' this by tweaking this number until
   * you get the PWM update frequency you're expecting!
   * The int.osc. for the PCA9685 chip is a range between about 23-27MHz and
   * is used for calculating things like writeMicroseconds()
   * Analog servos run at ~50 Hz updates, It is importaint to use an
   * oscilloscope in setting the int.osc frequency for the I2C PCA9685 chip.
   * 1) Attach the oscilloscope to one of the PWM signal pins and ground on
   *    the I2C PCA9685 chip you are setting the value for.
   * 2) Adjust setOscillatorFrequency() until the PWM update frequency is the
   *    expected value (50Hz for most ESCs)
   * Setting the value here is specific to each individual I2C PCA9685 chip and
   * affects the calculations for the PWM update frequency. 
   * Failure to correctly set the int.osc value will cause unexpected PWM results
   */
  pwm.setOscillatorFrequency(27000000);
  pwm.setPWMFreq(SERVO_FREQ);  // Analog servos run at ~50 Hz updates

  delay(10);
}

void loop() {
  debug_pin_state();
  //state transition
  switch(serial_state)
  {
    case IDLE:
      //transition the state to init state
      serial_state = INIT;
      break;
    case INIT:
      serial_state = READY;
      break;
    case READY:
      //if receive signal from PC, send state to Stream
      if(PC_signal_flag)
      {
        serial_state = STREAM;
        //reset signal flag
        PC_signal_flag = false;
      }
      else
      {
        //stay in the same state otherwise
        serial_state = READY;
      }
      break;
    case STREAM:
      // if the time out flag is true, send state to TIMEOUT
      if(serial_timeout_flag)
      {
        serial_state = TIMEOUT;
        //reset timeout flag
        serial_timeout_flag = false;
      }
      else
      {
        //stay at the same state
        serial_state = STREAM;
      }
      break;
    case TIMEOUT:
      // send the state back to idle
      serial_state = IDLE;
      break;
  }  
  //state behavior
  switch(serial_state)
  {
    case IDLE:
      // do nothing
      break;
    case INIT:
      // Serial.print("INIT");
      // Serial.println();
      // clear the RX buffer
      while(Serial.available()>0){
        // read the port until it's empty
        dump = Serial.read();
      }
      //flush the output buffer
      Serial.flush();
      // disable the timer
      timer_dis();
      // reset the timer counter
      timer_reset();

      //sent out init signal
      Serial.write(INIT_UNO);
      
      break;
    case READY:
      // Serial.print("READY");
      // Serial.println();
      // polling for the signal byte
      if (Serial.available())
      {
        if(Serial.read() == SIG_PC)
        {
          // set the signal flag
          PC_signal_flag = true;
          // send out acknowledge byte when receive the signal
          Serial.print(ACK_UNO);
          // enable timer interrupt
          // timer_int_en();
          // enable timer
          // timer_en();
        }
      }
      
      break;
    case STREAM:
      // Serial.print("STREAM");
      // Serial.println();
      // receive 8 bytes at a time
      // PC will send joint pose command at 50 Hz
      // data format: each joint position is a uint16, will be sent in two bytes,
      // format will be JP1_H,JP1_L...., unit: length count(I don't want arduino to handle floating point number)

      while(Serial.available() < (JOINT_NUM+1)*2) //"+1" here means the gripper command
      {
        //wait
      }
      Serial.readBytes(buff, (JOINT_NUM+1)*2);
      // digitalWrite(debugPin_read_serial, 0);
      // update servo command
      // digitalWrite(debugPin_update_servo, 1);

      //start compose the joint pose from the receive data
      for(int i = 0; i < (JOINT_NUM+1); i++)
      {
        joint_poses[i] = ((((uint16_t)(buff[2*i])) << 8u) | (uint16_t)(buff[2*i+1]));
        // Serial.print(joint_poses[i]);
      }
      //update the servo command
      for(int i = 0; i < (JOINT_NUM+1); i++)
      {
        
        pwm.setPWM(i, 0, joint_poses[i]);
        // pwm.setPWM(i, 0, 598);
      }
      // digitalWrite(debugPin_update_servo, 0);
      //make sure the input buffer is cleared
      while(Serial.available()>0){
        // read the port until it's empty
        dump = Serial.read();
      }
      // send out acknowledge byte
      Serial.print(ACK_UNO);
      break;
    case TIMEOUT:
      // Serial.print("TIMEOUT");
      // Serial.println();
      // disable timer interrupt
      timer_int_dis();
      break;
  }

}

//With the settings above, this IRS will trigger each 500ms.
ISR(TIMER1_COMPA_vect){
  TCNT1  = 0;                  //First, set the timer back to 0 so it resets for next interrupt
  //set the timeout flag
  digitalWrite(debugPin_timeout, 1);
  serial_timeout_flag = true;
}

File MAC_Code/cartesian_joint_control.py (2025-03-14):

"""""""""""""""""""""""""""""

University of Washington, 2024

Author: Tin Chiang

Note: Modified code from Haonan Peng's Raven keyboard controller

Original code: https://github.dev/uw-biorobotics/raven2_CRTK_Python_controller/blob/main/python_controller/run_r2_keyboard_controller.py
"""""""""""""""""""""""""""""

# import time
# import numpy as np
# from pynput import keyboard
# import sys, os
# from robot_controller import robot_controller


# def print_manu():
#     print('  ')
#     print('-----------------------------------------')
#     print('EE543 Arm Keyboard Controller:')
#     print('-----------------------------------------')
#     print('[Exit]: 9')
#     print('[Joint 1    +]: 1 | [Joint 1     -]: q')
#     print('[Joint 2    +]: 2 | [Joint 2     -]: w')
#     print('[Joint 3    +]: 3 | [Joint 3     -]: e')
#     print('[Joint 4    +]: 4 | [Joint 4     -]: r')
#     print('[Grasper Open]: 5 | [Grasper Close]: t')

#     print('-----------------------------------------')
#     print('-----------------------------------------')
#     print('Current command:\n')
#     return None

# def print_no_newline(string):
#     sys.stdout.write("\r" + string)
#     sys.stdout.flush()
#     return None


# # init the Robot Controller
# RC = robot_controller()
# RC.communication_begin()

# # Force homing the robot
# RC.joints_homing()

# keyboard_increment = 0.5

# goals = np.zeros(RC.joint_num)
# speeds = np.ones(RC.joint_num) * 80 # deg/s


# x = 0
# working = 1
# command = False
# print_manu()

# while working==1:

#     #get the keyboard input
#     input_key = keyboard.read_event().name

#     if input_key == '9':
#         # RC.communication_end()
#         os.system('cls' if os.name == 'nt' else 'clear')
#         sys.exit('Closing Keyboard controller')
        

#     elif input_key == '1':
#         print_no_newline(" Moving: Joint 1 +++         ")
#         goals[0] += keyboard_increment
#         command = True


#     elif input_key == 'q':
#         print_no_newline(" Moving: Joint 1 ---         ")
#         goals[0] -= keyboard_increment
#         command = True

#     elif input_key == '2':
#         print_no_newline(" Moving: Joint 2 +++         ")
#         goals[1] += keyboard_increment
#         command = True
              
#     elif input_key == 'w':
#         print_no_newline(" Moving: Joint 2 ---         ")
#         goals[1] -= keyboard_increment
#         command = True

#     elif input_key == '3':
#         print_no_newline(" Moving: Joint 3 +++         ")
#         goals[2] += keyboard_increment
#         command = True
        
#     elif input_key == 'e':
#         print_no_newline(" Moving: Joint 3 ---         ")
#         goals[2] -= keyboard_increment
#         command = True

#     elif input_key == '4':
#         print_no_newline(" Moving: Joint 4 +++         ")
#         goals[3] += keyboard_increment
#         command = True
        
#     elif input_key == 'r':
#         print_no_newline(" Moving: Joint 4 ---         ")
#         goals[3] -= keyboard_increment
#         command = True
    
#     elif input_key == 'h':
#         print_no_newline(" Homing....                  ")
#         goals = RC.robot_homing_joint_poses.copy()
#         command = True
        
#     elif input_key == '5':
#         print_no_newline(" Grasper Open....                  ")
#         RC.gripper_open()
#         # goals = RC.robot_homing_joint_poses.copy()
#         # command = True

#     elif input_key == 't':
#         print_no_newline(" Grasper Close....                  ")
#         RC.gripper_close()
#         # goals = RC.robot_homing_joint_poses.copy()
#         # command = True

#     else:
#         print_no_newline(' Unknown command             ')

    
#     if command:
#         # make sure the goals is within joint limit
#         goals = np.clip(goals, RC.servo_angle_min, RC.servo_angle_max) 
#         sys.stdout.write("\033[1B") # move curser down
#         RC.joints_goto(goals, speeds)
#         sys.stdout.write("\033[1A") # move curser up
#         command = False

import time
import numpy as np
import sys
import os
from symbolic import *
from pynput import keyboard
import matplotlib.pyplot as plt
from mpl_toolkits.mplot3d import Axes3D
from robot_controller_win import robot_controller

# Global variable to track the last key pressed
last_key = None

def on_press(key):
    global last_key
    try:
        last_key = key.char
    except AttributeError:
        pass

def print_menu():
    os.system('clear')
    print('''
-----------------------------------------
EE543 Arm Keyboard Controller:
-----------------------------------------
[Exit]: 9
[Joint 1    +]: 1 | [Joint 1     -]: q
[Joint 2    +]: 2 | [Joint 2     -]: w
[Joint 3    +]: 3 | [Joint 3     -]: e
[Joint 4    +]: 4 | [Joint 4     -]: r
[Grasper Open]: 5 | [Grasper Close]: t
[Homing]: h
-----------------------------------------
Current command:''')

def print_no_newline(string):
    sys.stdout.write("\r" + string + " " * 20)  # Add padding to clear previous text
    sys.stdout.flush()

def plot_joint_frames(transforms, ax, axis_length=20):
    for i, T in enumerate(transforms):
        origin = T[0:3, 3]
        R = T[0:3, 0:3] 
        x_axis = R[:,0] 
        y_axis = R[:,1]
        z_axis = R[:,2]
        ax.quiver(
            origin[0], origin[1], origin[2],
            x_axis[0], x_axis[1], x_axis[2],
            color='b', length=axis_length, normalize=True
        )
        # ax.quiver(
        #     origin[0], origin[1], origin[2],
        #     y_axis[0], y_axis[1], y_axis[2],
        #     color='g', length=axis_length, normalize=True
        # )
        ax.quiver(
            origin[0], origin[1], origin[2],
            z_axis[0], z_axis[1], z_axis[2],
            color='r', length=axis_length, normalize=True
        )

def plot_arm_skeleton(transforms, ax):
    points = [T[0:3, 3] for T in transforms]
    points = np.array(points)
    plt_x_lim = [-200, 200]
    plt_y_lim = [-200, 200]
    plt_z_lim = [0, 300]
    xs = points[:,0]
    ys = points[:,1]
    zs = points[:,2]
    ax.set_xlim(plt_x_lim)
    ax.set_ylim(plt_y_lim)
    ax.set_zlim(plt_z_lim)    
    ax.plot(xs, ys, zs, 'o-', color='k', linewidth=3, markersize=6)
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

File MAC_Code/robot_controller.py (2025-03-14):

import time
import numpy as np
import serial
import sys
from scipy.spatial import ConvexHull
import matplotlib.pyplot as plt
from mpl_toolkits.mplot3d import Axes3D
from forward_k import *
from scipy.optimize import minimize
np.set_printoptions(precision=2, suppress=False)
np.set_printoptions(formatter={'all': lambda x: f'{x:.2f}'})

class robot_controller():
    def __init__(self) -> None:
        #define robot parameter
        self.joint_num = 4
        self.joints_goto_tolerance = 10e-3

        #define robot state
        self.robotstate_joint_poses = np.zeros(self.joint_num)
        self.robotstate_joint_vels = np.zeros(self.joint_num)
        self.robotState_endeffector_orientation = np.zeros(3)
        self.robotstate_endeffector_pose = np.zeros(3)
        self.robotstate_gripper_close = False

        #define homing position in joint space
        self.robot_homing_joint_poses = np.zeros(self.joint_num)

        """
        ---------------------------------------------------------------
         Below are the parameters related to robot link geometry
        ---------------------------------------------------------------
        """

        #define the DH parameter for the arm link
        # [a, alpha, d, theta (will be replaced by joint_positions)]
        self.dh_params = [
            [0,    0,  62.8,    0],     # Joint 1 (revolute)
            [0,   90,     0,    0],     # Joint 2 (revolute)
            [101,  0,     0,    0],     # Joint 3 (revolute)
            [0,   90,  87.5,    0],     # Joint 4 (revolute)
            [0,    0,   125,    0]      # Fixed link from joint 4 to end-effector
        ]

        self.angle_offsets = np.array([0, 90, 90, 0]) # this is for 4 joints setting

        # the transformation matrices from first to last link 
        self.T_matrices = np.empty(self.joint_num) # no value when init

        #define the base frame
        self.base_frame = np.eye(self.joint_num)

        """
        ---------------------------------------------------------------
         Below are the parameters related to hardware and communciation
        ---------------------------------------------------------------
        """

        #here define the specification for MG996R servo motors
        self.servo_angle_max = 90 #degree
        self.servo_angle_min = -90 #degree
        self.servo_pulse_max = 440 #+90 for mg996R, This is the 'maximum' pulse length count (out of 4096)
        self.servo_pulse_min = 70 #-90 for mg996R, This is the 'minimum' pulse length count (out of 4096)

        # Here define the operating parameters for sliding gripper
        # Slider gripper is also controlled by an MG996R servo motor
        self.gripper_open_angle = 0 # degree
        self.gripper_close_angle = -90 # degree
        
        # Pre-compute the servo pulse lengths for convenience
        self.gripper_pulse_open = self.angle_to_pulse_length(np.array([self.gripper_open_angle]))[0]
        self.gripper_pulse_close = self.angle_to_pulse_length(np.array([self.gripper_close_angle]))[0]

        #define the serial communication parameter
        self.com_port = '/dev/cu.usbserial-A5069RR4' # change it if needed
        self.com_baudrate = 115200 #bps
        self.com_frequency = 30 #Hz
        

    """
    ---------------------------------------------------------------
     Functions below set up the serial communication
    ---------------------------------------------------------------
    """

    def communication_begin(self):
        self.ser = serial.Serial(self.com_port, self.com_baudrate)
        # Reset input/output buffer and wait for initialization
        self.ser.reset_input_buffer()
        self.ser.reset_output_buffer()
        time.sleep(1)

        # Wait for Arduino to initialize
        while True:
            if self.ser.read() == b'I':
                break

        # Send signaling byte
        self.ser.write(b'S')
        time.sleep(0.1)
        
    def communication_end(self):
        self.ser.close()

    """
    ---------------------------------------------------------------
     Functions below set up the visualization
    ---------------------------------------------------------------
    """
        
    """
    ---------------------------------------------------------------
     Functions below setup the transformation matrix for 
     forward kinematics
    ---------------------------------------------------------------
    """

    # input: DH parameters of a specific link, angle in degree, length in mm
    # output: the transformation matrix of that link
    def dh_to_transformation_matrix(self, alpha, a, d, theta, deg=True):
        if deg:
            alpha = np.deg2rad(alpha)
            theta = np.deg2rad(theta)
        ca = np.cos(alpha)
        sa = np.sin(alpha)
        ct = np.cos(theta)
        st = np.sin(theta)
        T = np.array([
            [   ct,       -st,        0,         a],
            [st*ca,     ct*ca,      -sa,     -sa*d],
            [st*sa,     ct*sa,       ca,      ca*d],
            [    0,         0,        0,         1]
        ], dtype=float)

        return T
    
    def ForwardK_N(self, joint_angles_deg):
        """Compute the forward kinematics transformation matrix for given joint angles (in degrees)."""
        dh = np.array(self.dh_params, dtype=float)
        for i in range(self.joint_num):
            dh[i, 3] = joint_angles_deg[i] + self.angle_offsets[i]
        T_final = np.eye(4)
        for row in dh:
            a, alpha, d, theta = row
            T_i = self.dh_to_transformation_matrix(alpha, a, d, theta)
            T_final = T_final @ T_i
        return T_final
    
    def update_forward_kinematics(self):
        """Calculate forward kinematics for all joints"""
        dh = np.array(self.dh_params, dtype=float)
        for i in range(self.joint_num):
            dh[[i], [3]] = self.robotstate_joint_poses[i] + self.angle_offsets[i]
        T_final = np.eye(4)
        for row in dh:
            a, alpha, d, theta = row
            T_i = self.dh_to_transformation_matrix(alpha, a, d, theta)
            T_final = T_final @ T_i

        self.robotstate_endeffector_pose = T_final[0:3, 3]

        R = T_final[0:3, 0:3]
        beta = -np.asin(R[2,0])                      
        alpha =  np.atan2(R[2,1], R[2,2])            
        gamma =  np.atan2(R[1,0], R[0,0])            
        self.robotState_endeffector_orientation = np.array([
            np.degrees(alpha),
            np.degrees(beta),
            np.degrees(gamma)
        ])
        
    def get_link_positions(self):

        dh = np.array(self.dh_params, dtype=float)
        for i in range(self.joint_num):
            dh[i, 3] = self.robotstate_joint_poses[i] + self.angle_offsets[i]

        T = np.eye(4)

        points = [T[0:3, 3].copy()]
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

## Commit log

2025-02-16 CAD files for the ARM
    [MG996 v1 v12.f3d, MG996 v1 v12.step, Servo Bracket - long U v3.f3d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]
2025-02-16 arm assembly
    [Arm Assembly v3.f3z, Offset Joint.f3d]
2025-02-16 next arm
    [Arm Assembly v5.f3z]
2025-02-16 Gripper CAD files
    [Base.SLDPRT, Estrella.SLDPRT, Part2.SLDPRT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]
2025-02-28 arm v1
    [Arm Assembly v7.f3z, Offset Joint v4.f3d]
2025-03-03 Mac code for Fwd Kinematics simulation & Monte Carlo WS
2025-03-04 Working Forward Kinematics & Monte Carlo Simulation Code.
2025-03-04 Updated working Forward Kinematics & Monte carlo simulation python code.
2025-03-08 Working code for Project Milestone 2 - Forward Kinematics Simulation, Plotting Robot Workspace using MonteCarlo Simulation - with Test Points.
2025-03-11 define forward kinematics
2025-03-11 moving to correct folders
    [cartesian_joint_control.py, forward_k.py, symbolic.py]
